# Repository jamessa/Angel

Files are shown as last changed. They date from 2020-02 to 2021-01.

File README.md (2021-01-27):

# Angel (2021)

Hand wired QMK is almost ready.  https://github.com/qmk/qmk_firmware/pull/11501

A symmetric staggered ergonomic keyboard.
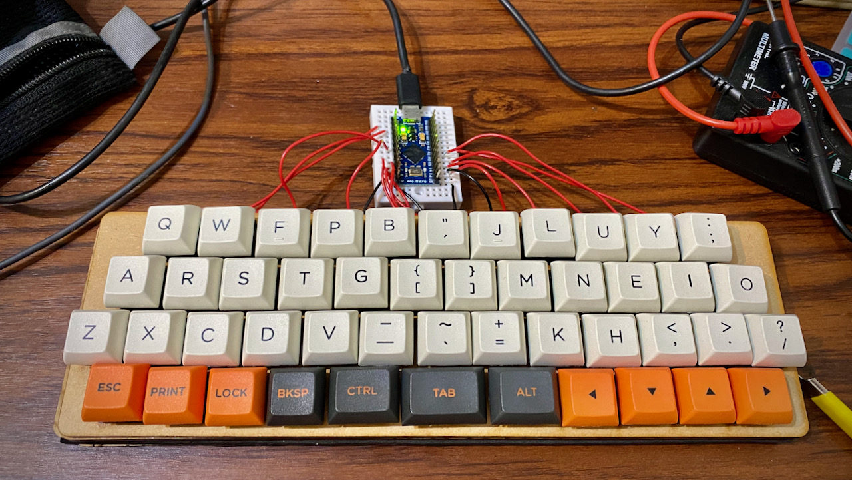
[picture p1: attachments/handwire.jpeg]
a symmetric and beautiful hand wire keyboard


## Idea

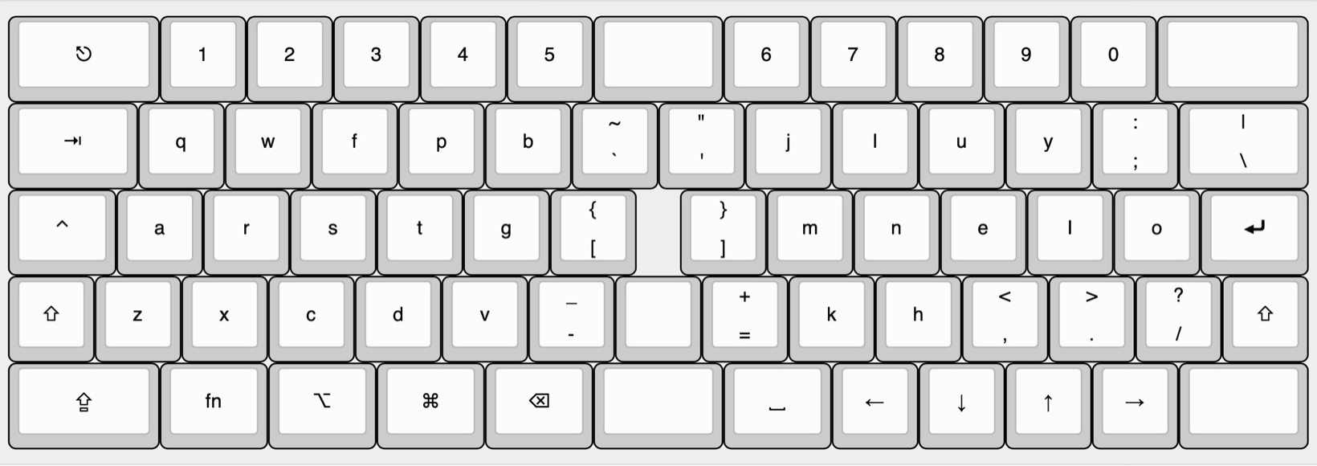
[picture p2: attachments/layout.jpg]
layout concept
A slightly ergonomic keyboard that fits into 60% form factor.  

 ## Featuring

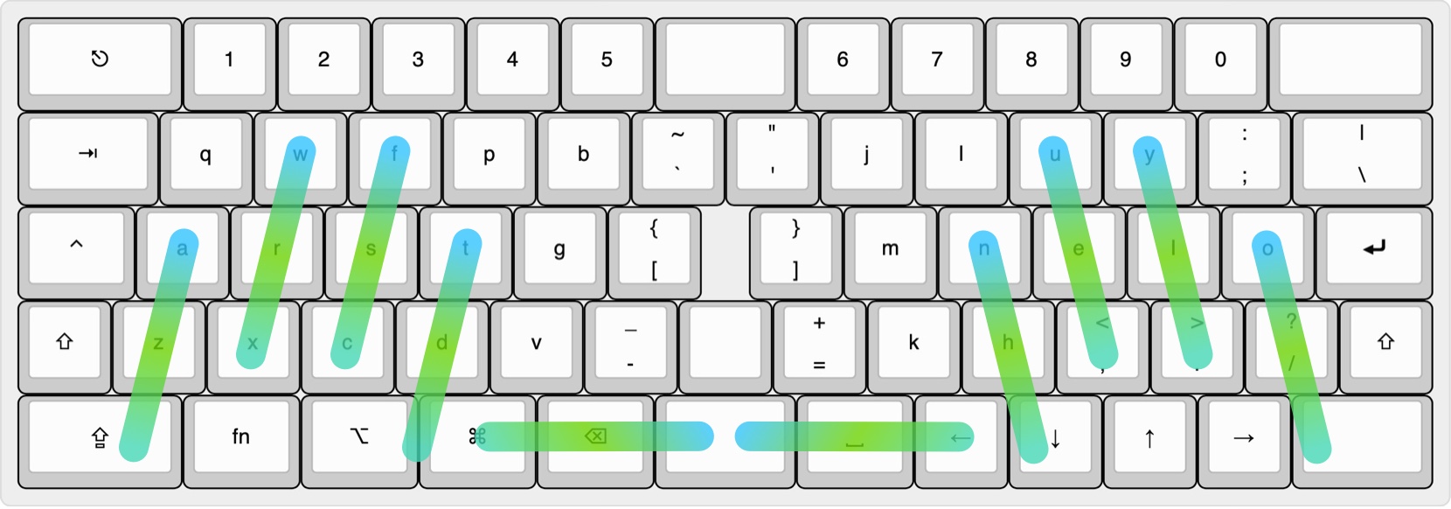
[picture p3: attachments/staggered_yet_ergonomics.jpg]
Symmetric stagger is ergonomic
* Staggered yet ergonmic 

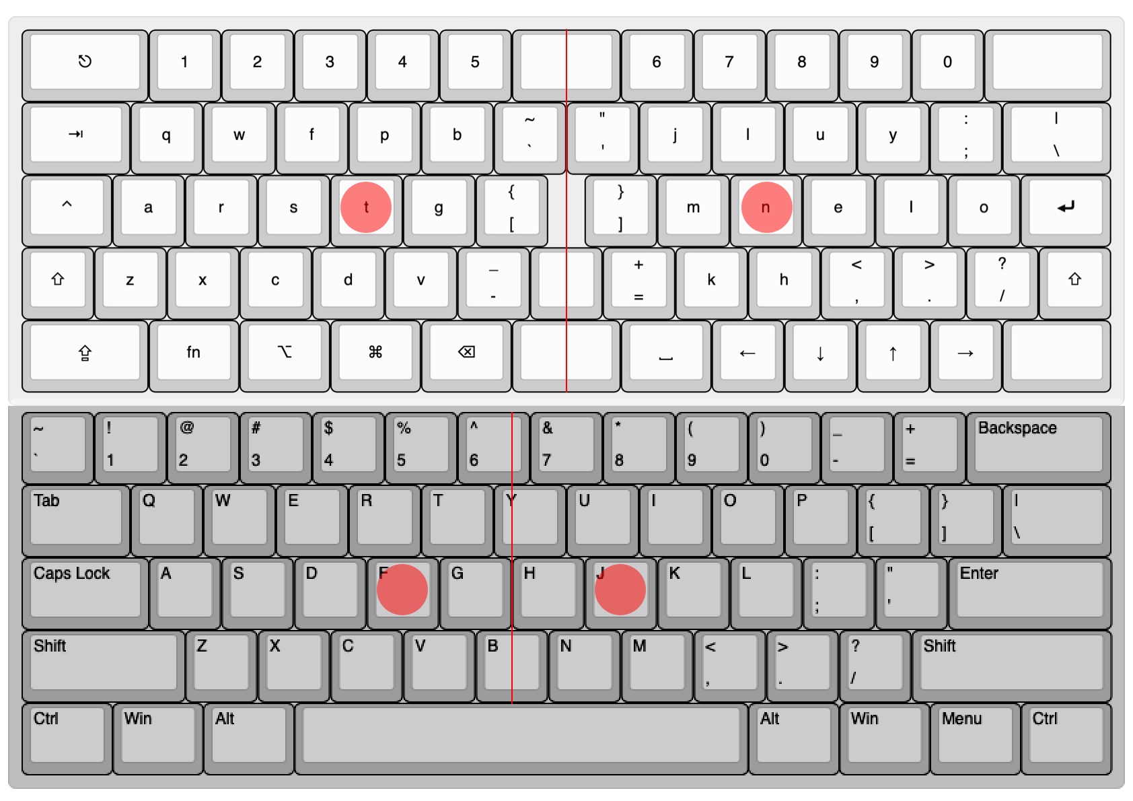
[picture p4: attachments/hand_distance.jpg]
hand distance
* Maximize hand distance 

* Arrow keys are must.

* Fitts' law is respected. Four corner keys are maximized while [you shall no call its name] is break into 3 keys.  The gaint space bar is a huge waste ot thumb(s). It breaks into 1.25, 1.5, 1.25 to free it up. My favorite combination is, <kbd>backspace</kbd>, <kbd>enter</kbd>, <kbd>whitespace</kbd>.

* 60% form factor which should fix your notebook perfectly.
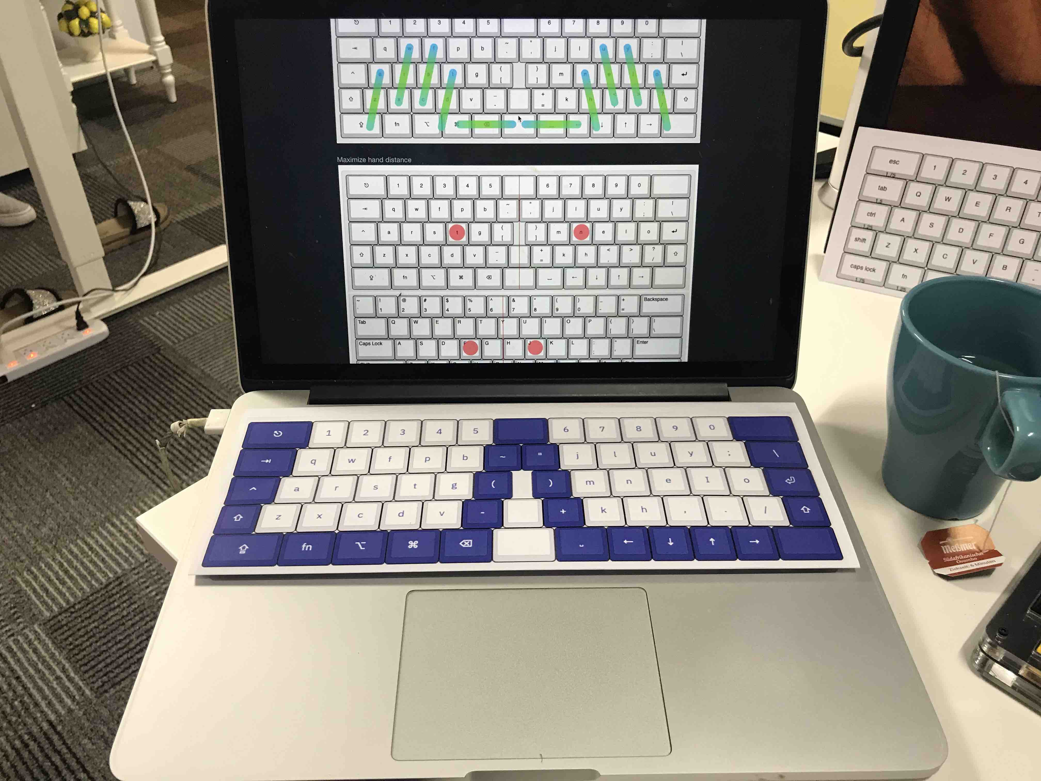
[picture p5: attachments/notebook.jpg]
notebook


* all keys are under 1.75u which means no stablizer is required. Period.

##  Cons

It's incompatible to traditioal keycaps layout. **CAPS LOCK** is the only 1.75u key on traditional keyboard. In Symmetric 60%, 4 is required but you can always swap into smaller keycaps at your wish.

## Prior work

in the order of first appearance.

[Symmetric Stagger 60%]( https://geekhack.org/index.php?topic=66965.0)  by Jesse Vincent, Keyboardio Symmetric Stagger While I wait for the Model 01 boards to come back from Shenzhen, I've been messing around with a symmetric stagger 60% layout. Before I go and get 5 PCBs made, I'd love layout feedback from folks.

### Meti
[SemiErgo](https://github.com/mtei/SemiErgo_Layout) by meti (March 2017)   SemiErgo I will vote it for ANSI standard without any doubt.

[Symmetric 70 hand-wire](https://github.com/qmk/qmk_firmware/tree/master/keyboards/handwired/symmetric70_proto) (2020)
Symmetric 70

### Rominronin
[Katana 60](https://deskthority.net/viewtopic.php?t=16287&start=30) (Nov, 2017). it's a beauty. Katana 60 ps. the character in the middle is 刀 which means sword in Chinese and Japanese.

[Tsuka60 - the Katana60 v2 PCB interest check](https://geekhack.org/index.php?topic=100468.msg2756587#msg2756587) (2019)

[Candykeys](https://candykeys.com/product/katana60-pcb-V2) (2020)

Katana60 v2 PCB
## Next

Now I am going to handwire one to refuse my point. Stay tune.

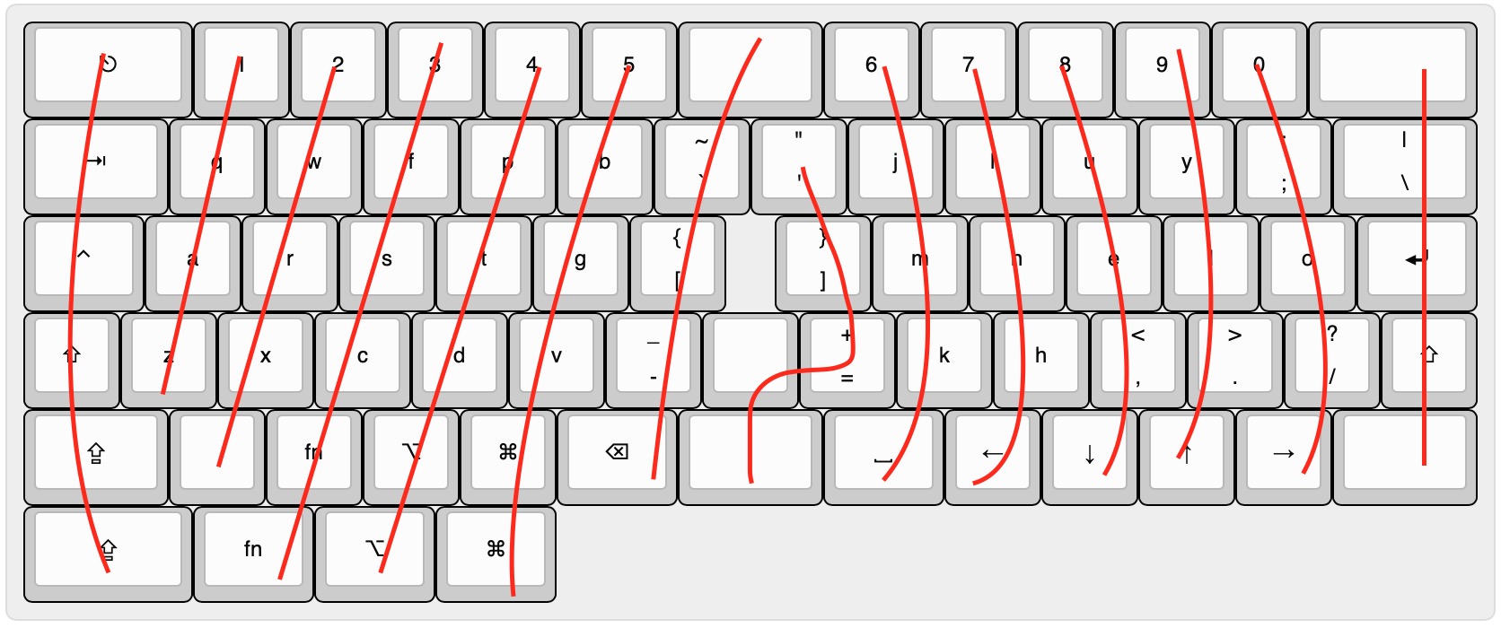
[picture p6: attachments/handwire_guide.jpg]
handwire guide


You can [try it on paper](try_it.pdf) and [let me know](https://forms.gle/i4KZJjDPFTidD8Jt6) how to you think about Symmetric60.

## References

On space bar http://xahlee.info/kbd/keyboard_problems.html

Key symbols from http://xahlee.info/comp/unicode_computing_symbols.html

Mac keyboard shortcuts https://support.apple.com/en-us/HT201236

Human Engineering the Keyboard by K. H. Eberhard Kroemer
 Human Factors: The Journal of the Human Factors and Ergonomics Society 1972 14: 51 DOI: [10.1177/001872087201400110](
http://hfs.sagepub.com/content/14/1/51)

## Prototyping Tips

### Kicad

  - Hardware acceleration will eeschema freezes, so don't enable it. Reset settings by `rm -rf ~/Library/Preferences/kicad` or verisioning it.
  - Plot gerber files and drills based on [JCLPCB's tutorial](https://support.jlcpcb.com/article/102-kicad-515---generating-gerber-and-drill-files). [Suggested naming patterns](https://support.jlcpcb.com/article/29-suggested-naming-patterns)

Special thanks to Haway 梁, Jeff 邱, Justin 吳.

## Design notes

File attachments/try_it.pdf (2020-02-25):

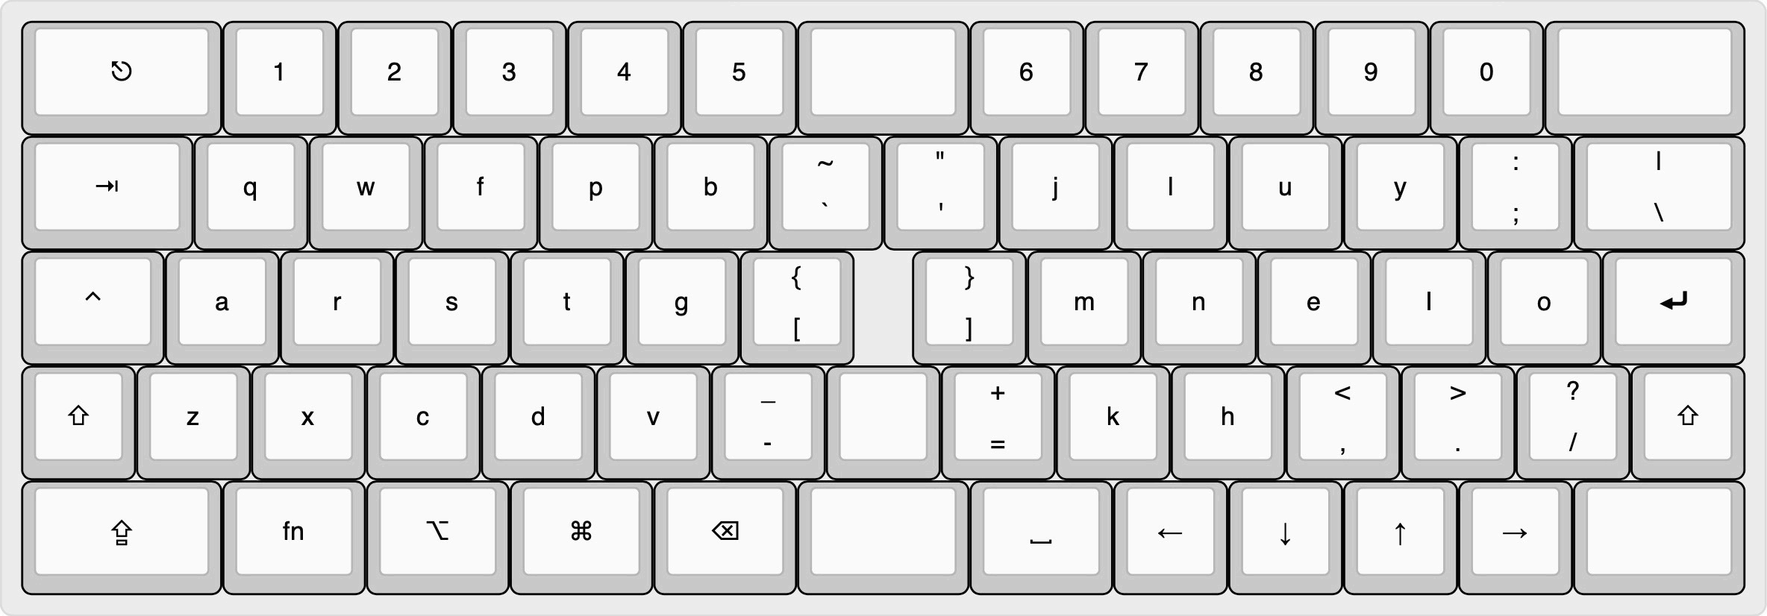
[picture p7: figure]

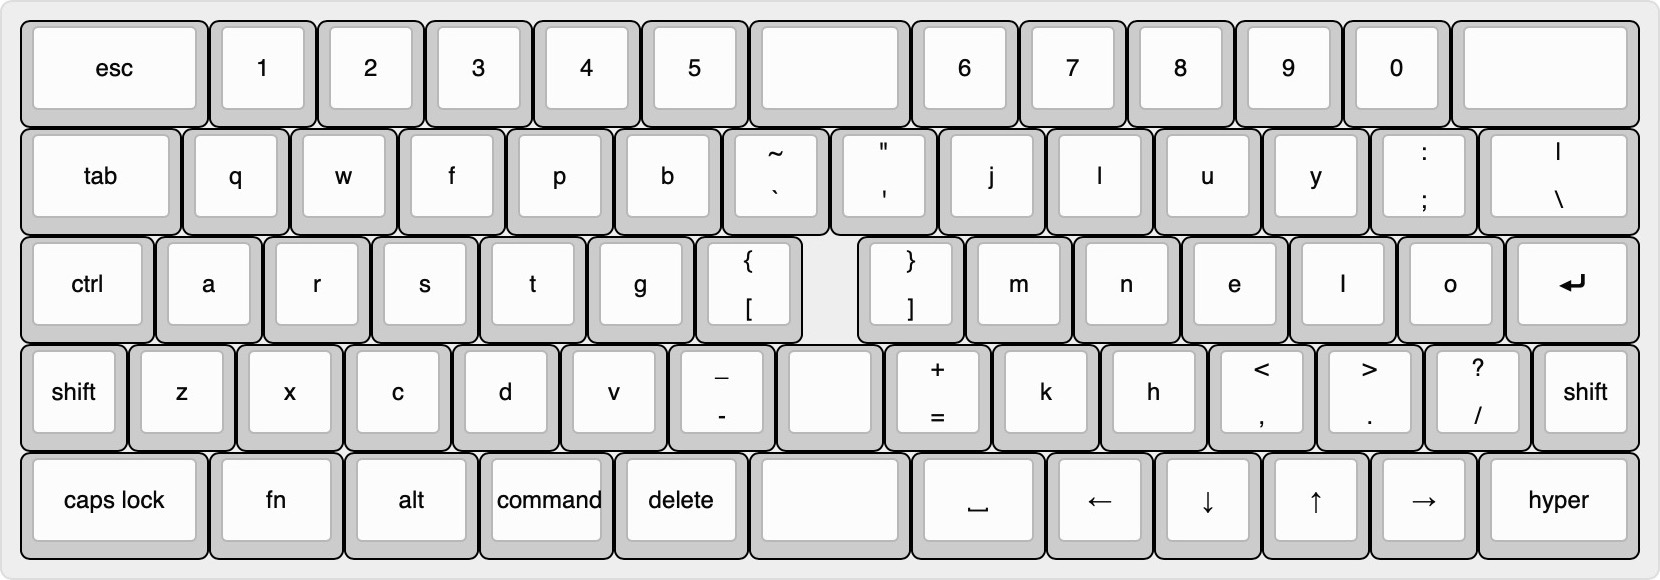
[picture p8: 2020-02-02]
attachments/symmetry_layout.jpg

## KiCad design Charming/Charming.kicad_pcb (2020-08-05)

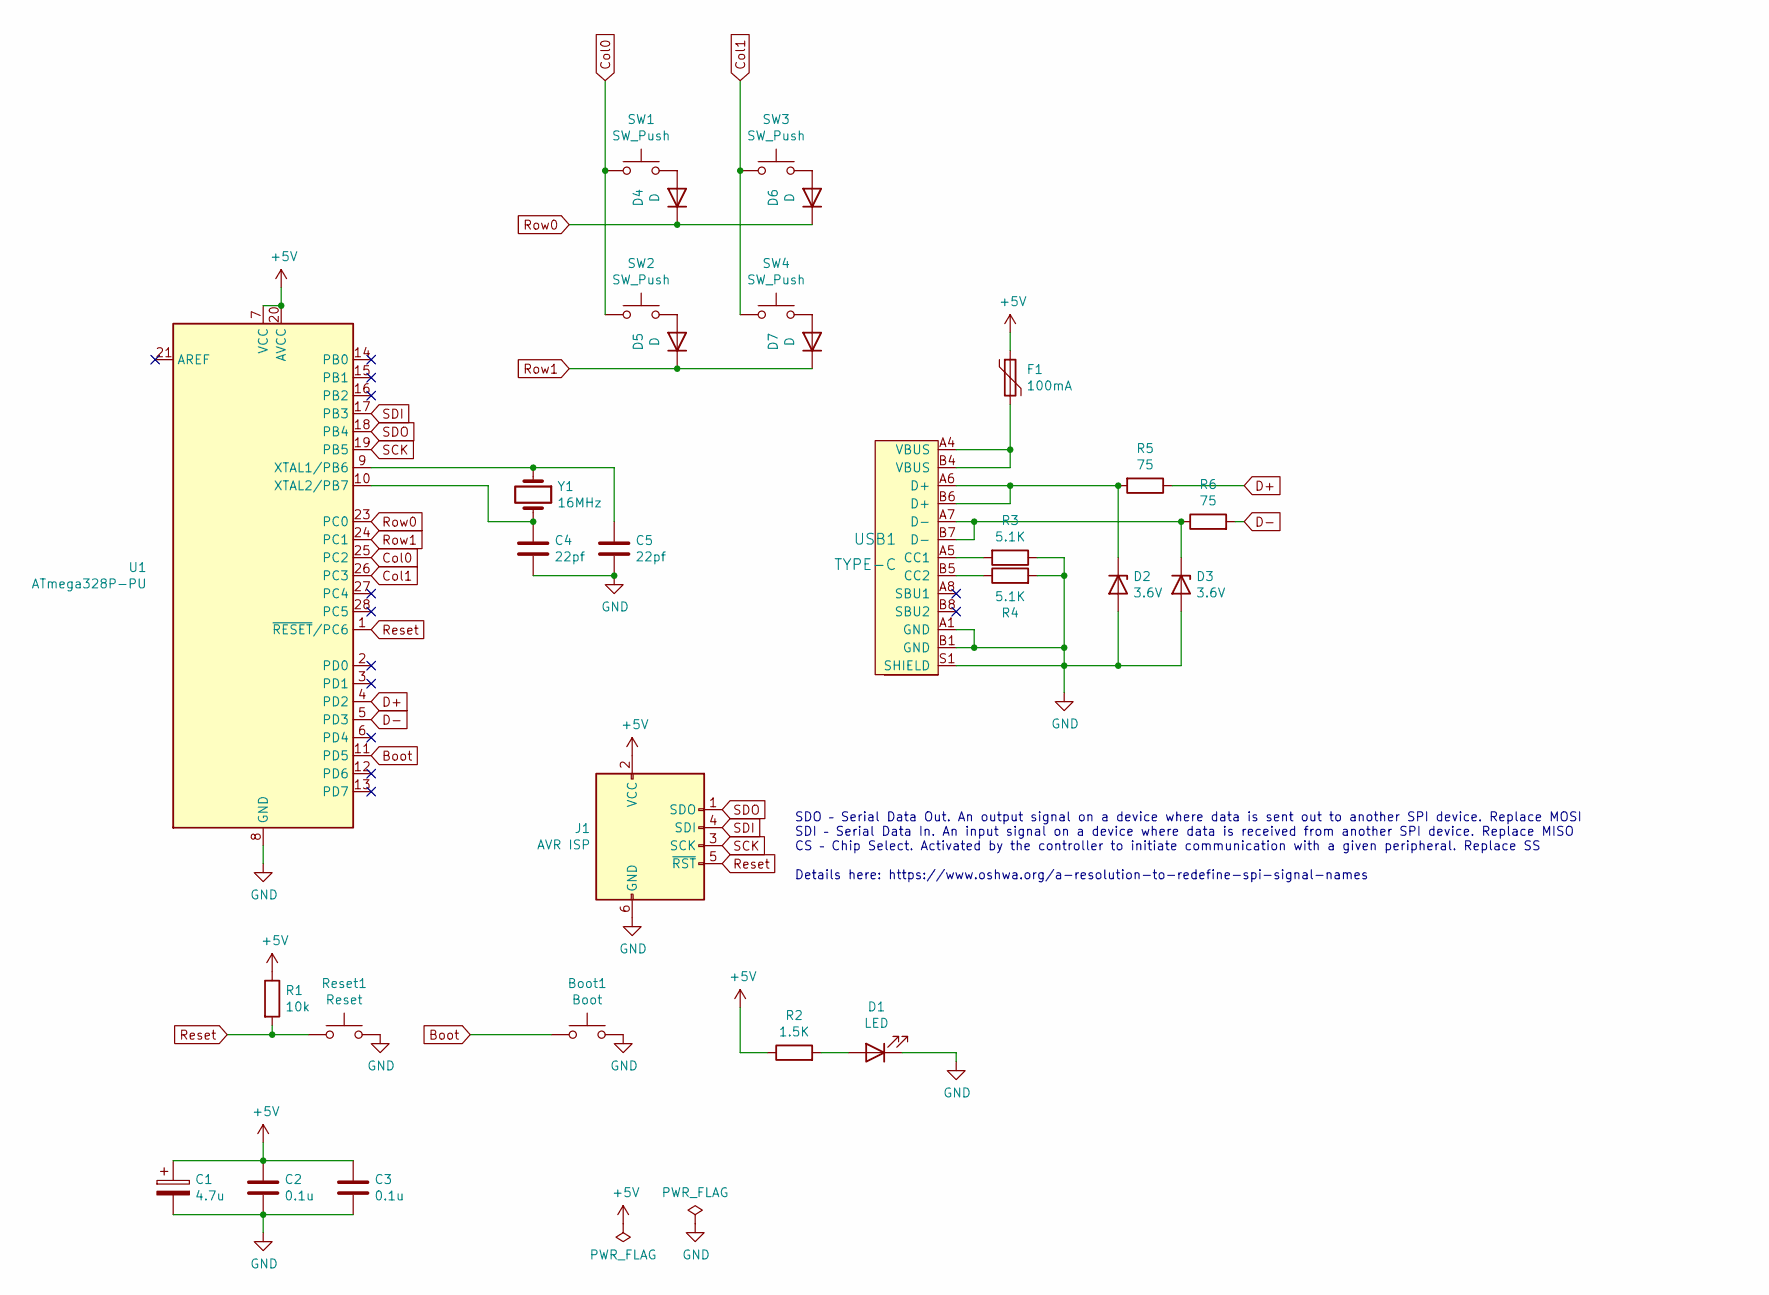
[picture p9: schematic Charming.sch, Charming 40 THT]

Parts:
Boot1: Boot; SW_PUSH_6mm
C1: 4.7u; CP_Radial_D4.0mm_P1.50mm
C2, C3: 0.1u; C_Disc_D4.3mm_W1.9mm_P5.00mm
C4, C5: 22pf; C_Disc_D3.0mm_W1.6mm_P2.50mm
D1: LED; LED_D3.0mm
D2, D3: 3.6V; D_DO-35_SOD27_P7.62mm_Horizontal
D4, D5, D6, D7: D; D_DO-35_SOD27_P7.62mm_Horizontal
F1: 100mA; Fuse_Bourns_MF-RG500
J1: AVR ISP; AVRISP
R1: 10k; R_Axial_DIN0204_L3.6mm_D1.6mm_P5.08mm_Horizontal
R2: 1.5K; R_Axial_DIN0204_L3.6mm_D1.6mm_P5.08mm_Horizontal
R3, R4: 5.1K; R_Axial_DIN0204_L3.6mm_D1.6mm_P5.08mm_Horizontal
R5, R6: 75; R_Axial_DIN0204_L3.6mm_D1.6mm_P5.08mm_Horizontal
Reset1: Reset; SW_PUSH_6mm
SW1, SW2, SW3, SW4: SW_Push; SW_Cherry_MX_1.00u_PCB
U1: ATmega328P-PU; DIP-28_W7.62mm
USB1: TYPE-C; USB_C_Receptacle_HRO_TYPE-C-31-M-12
Y1: 16MHz; Crystal_HC49-4H_Vertical

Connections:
+5V: C1.1, C2.1, C3.1, F1.1, J1.2 (VCC), R1.1, R2.1, U1.7 (VCC), U1.20 (AVCC)
Boot: Boot1.1, U1.11 (PD5)
Col0: SW1.1, SW2.1, U1.25 (PC2)
Col1: SW3.1, SW4.1, U1.26 (PC3)
D+: R5.1, U1.4 (PD2)
D-: R6.2, U1.5 (PD3)
GND: Boot1.2, C1.2, C2.2, C3.2, C4.1, C5.1, D1.1 (K), D2.2 (A), D3.2 (A), J1.6 (GND), R3.1, R4.2, Reset1.2, U1.8 (GND), U1.22 (GND), USB1.A1 (GND), USB1.B1 (GND), USB1.S1 (SHIELD)
unnamed: C4.2, U1.10 (XTAL2/PB7), Y1.2
unnamed: C5.2, U1.9 (XTAL1/PB6), Y1.1
unnamed: D1.2 (A), R2.2
unnamed: D2.1 (K), R5.2, USB1.A6 (D+), USB1.B6 (D+)
unnamed: D3.1 (K), R6.1, USB1.A7 (D-), USB1.B7 (D-)
unnamed: D4.2 (A), SW1.2
unnamed: D5.2 (A), SW2.2
unnamed: D6.2 (A), SW3.2
unnamed: D7.2 (A), SW4.2
unnamed: F1.2, USB1.A4 (VBUS), USB1.B4 (VBUS)
unnamed: R3.2, USB1.A5 (CC1)
unnamed: R4.1, USB1.B5 (CC2)
Reset: J1.5 (~RST), R1.2, Reset1.1, U1.1 (~RESET~/PC6)
Row0: D4.1 (K), D6.1 (K), U1.23 (PC0)
Row1: D5.1 (K), D7.1 (K), U1.24 (PC1)
SCK: J1.3 (SCK), U1.19 (PB5)
SDI: J1.4 (SDI), U1.17 (PB3)
SDO: J1.1 (SDO), U1.18 (PB4)

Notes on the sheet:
SDO – Serial Data Out. An output signal on a device where data is sent out to another SPI device. Replace MOSI SDI – Serial Data In. An input signal on a device where data is received from another SPI device. Replace MISO CS – Chip Select. Activated by the controller to initiate communication with 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

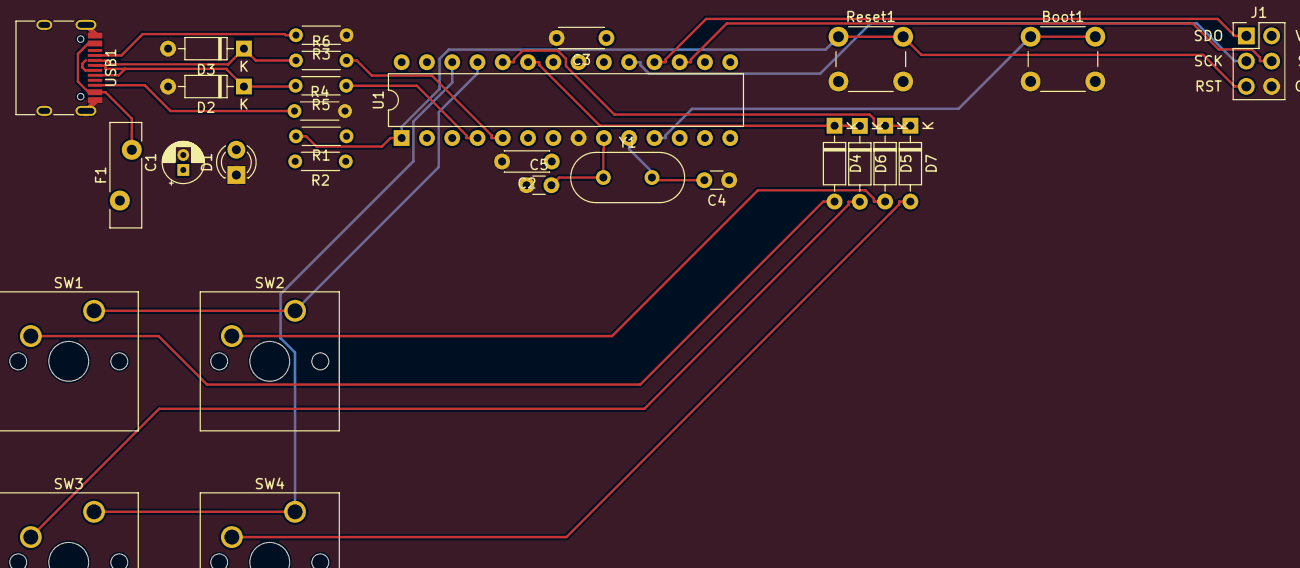
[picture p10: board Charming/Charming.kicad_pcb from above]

Board: 2 copper layers, 29 parts (0 on the bottom side), 25 nets.

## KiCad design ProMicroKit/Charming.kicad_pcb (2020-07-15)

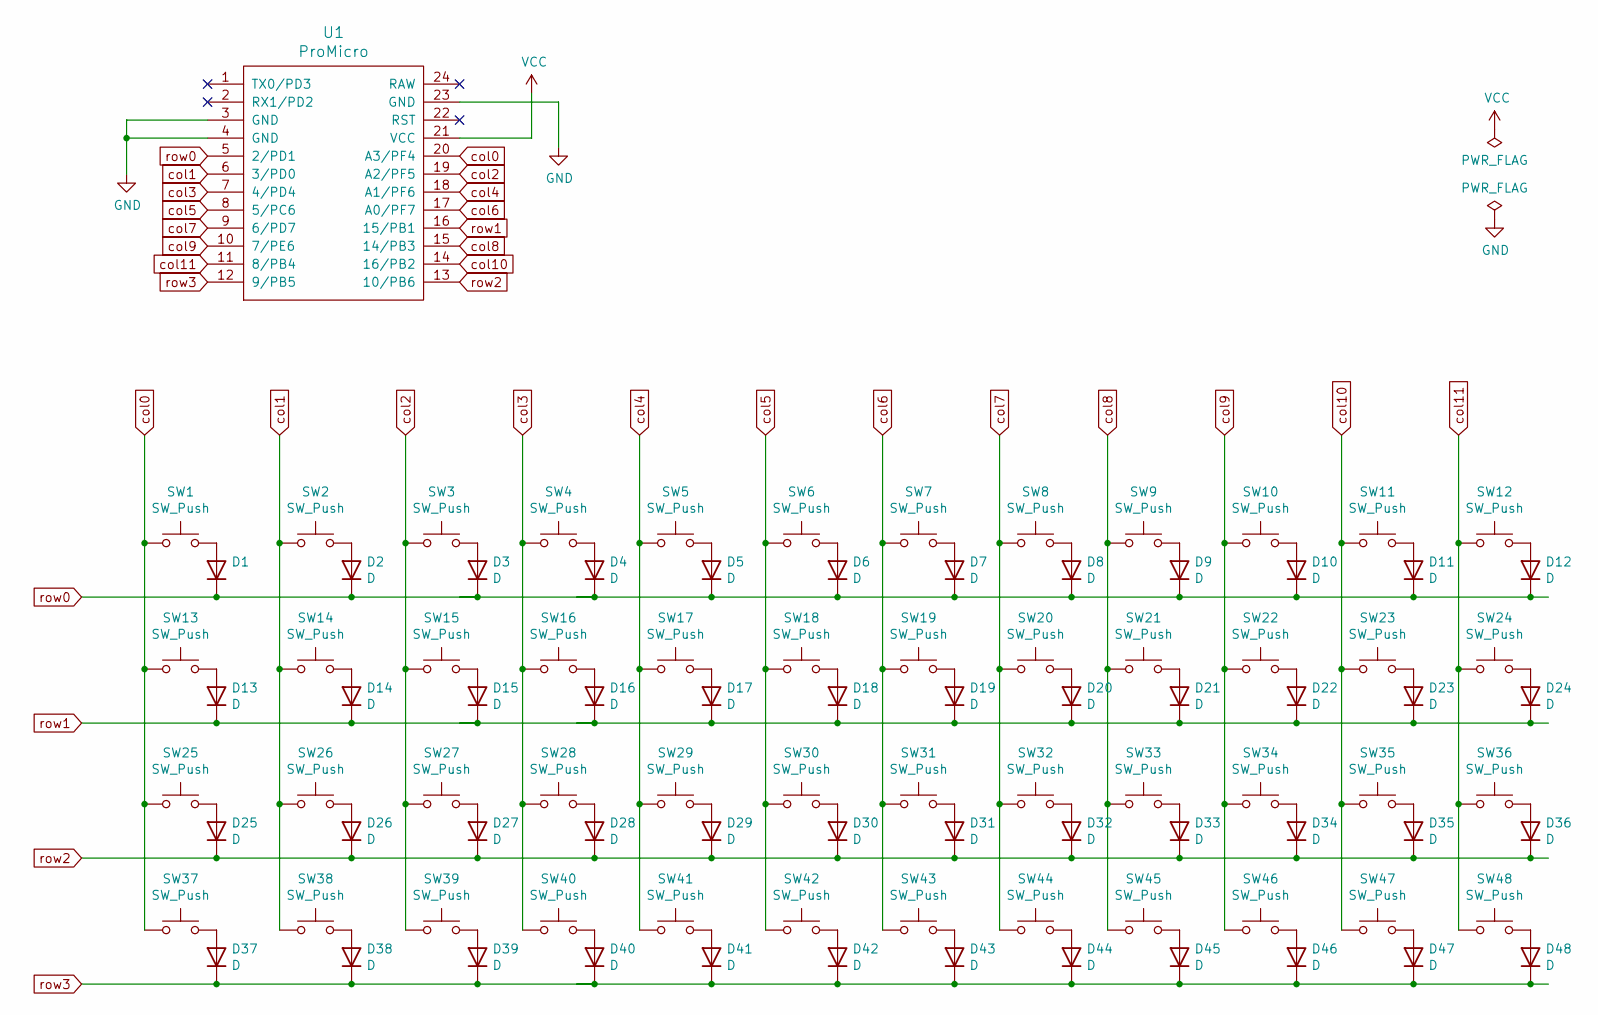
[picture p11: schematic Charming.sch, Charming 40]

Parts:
D1, D2, D3, D4, D5, D6, D7, D8, D9, D10, D11, D12, D13, D14, D15, D16, D17, D18, D19, D20, D21, D22, D23, D24, D25, D26, D27, D28, D29, D30, D31, D32, D33, D34, D35, D36, D37, D38, D39, D40, D41, D42, D43, D44, D45, D46, D47, D48: D; D_SOD-123
SW1, SW2, SW3, SW4, SW5, SW6, SW7, SW8, SW9, SW10, SW11, SW12, SW13, SW14, SW15, SW16, SW17, SW18, SW19, SW20, SW21, SW22, SW23, SW24, SW25, SW26, SW27, SW28, SW29, SW30, SW31, SW32, SW33, SW34, SW35, SW36, SW37, SW38, SW39, SW40, SW41, SW42, SW43, SW44, SW45, SW46, SW47, SW48: SW_Push; SW_PG1350
U1: ProMicro; ArduinoProMicro

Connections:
GND: U1.3 (GND), U1.4 (GND), U1.23 (GND)
unnamed: D1.2 (A), SW1.2
unnamed: D2.2 (A), SW2.2
unnamed: D3.2 (A), SW3.2
unnamed: D4.2 (A), SW4.2
unnamed: D5.2 (A), SW5.2
unnamed: D6.2 (A), SW6.2
unnamed: D7.2 (A), SW7.2
unnamed: D8.2 (A), SW8.2
unnamed: D9.2 (A), SW9.2
unnamed: D10.2 (A), SW10.2
unnamed: D11.2 (A), SW11.2
unnamed: D12.2 (A), SW12.2
unnamed: D13.2 (A), SW13.2
unnamed: D14.2 (A), SW14.2
unnamed: D15.2 (A), SW15.2
unnamed: D16.2 (A), SW16.2
unnamed: D17.2 (A), SW17.2
unnamed: D18.2 (A), SW18.2
unnamed: D19.2 (A), SW19.2
unnamed: D20.2 (A), SW20.2
unnamed: D21.2 (A), SW21.2
unnamed: D22.2 (A), SW22.2
unnamed: D23.2 (A), SW23.2
unnamed: D24.2 (A), SW24.2
unnamed: D25.2 (A), SW25.2
unnamed: D26.2 (A), SW26.2
unnamed: D27.2 (A), SW27.2
unnamed: D28.2 (A), SW28.2
unnamed: D29.2 (A), SW29.2
unnamed: D30.2 (A), SW30.2
unnamed: D31.2 (A), SW31.2
unnamed: D32.2 (A), SW32.2
unnamed: D33.2 (A), SW33.2
unnamed: D34.2 (A), SW34.2
unnamed: D35.2 (A), SW35.2
unnamed: D36.2 (A), SW36.2
unnamed: D37.2 (A), SW37.2
unnamed: D38.2 (A), SW38.2
unnamed: D39.2 (A), SW39.2
unnamed: D40.2 (A), SW40.2
unnamed: D41.2 (A), SW41.2
unnamed: D42.2 (A), SW42.2
unnamed: D43.2 (A), SW43.2
unnamed: D44.2 (A), SW44.2
unnamed: D45.2 (A), SW45.2
unnamed: D46.2 (A), SW46.2
unnamed: D47.2 (A), SW47.2
unnamed: D48.2 (A), SW48.2
VCC: U1.21 (VCC)
col0: SW1.1, SW13.1, SW25.1, SW37.1, U1.20 (A3/PF4)
col1: SW2.1, SW14.1, SW26.1, SW38.1, U1.6 (3/PD0)
col2: SW3.1, SW15.1, SW27.1, SW39.1, U1.19 (A2/PF5)
col3: SW4.1, SW16.1, SW28.1, SW40.1, U1.7 (4/PD4)
col4: SW5.1, SW17.1, SW29.1, SW41.1, U1.18 (A1/PF6)
col5: SW6.1, SW18.1, SW30.1, SW42.1, U1.8 (5/PC6)
col6: SW7.1, SW19.1, SW31.1, SW43.1, U1.17 (A0/PF7)
col7: SW8.1, SW20.1, SW32.1, SW44.1, U1.9 (6/PD7)
col8: SW9.1, SW21.1, SW33.1, SW45.1, U1.15 (14/PB3)
col9: SW10.1, SW22.1, SW34.1, SW46.1, U1.10 (7/PE6)
col10: SW11.1, SW23.1, SW35.1, SW47.1, U1.14 (16/PB2)
col11: SW12.1, SW24.1, SW36.1, SW48.1, U1.11 (8/PB4)
row0: D1.1 (K), D2.1 (K), D3.1 (K), D4.1 (K), D5.1 (K), D6.1 (K), D7.1 (K), D8.1 (K), D9.1 (K), D10.1 (K), D11.1 (K), D12.1 (K), U1.5 (2/PD1)
row1: D13.1 (K), D14.1 (K), D15.1 (K), D16.1 (K), D17.1 (K), D18.1 (K), D19.1 (K), D20.1 (K), D21.1 (K), D22.1 (K), D23.1 (K), D24.1 (K), U1.16 (15/PB1)
row2: D25.1 (K), D26.1 (K), D27.1 (K), D28.1 (K), D29.1 (K), D30.1 (K), D31.1 (K), D32.1 (K), D33.1 (K), D34.1 (K), D35.1 (K), D36.1 (K), U1.13 (10/PB6)
row3: D37.1 (K), D38.1 (K), D39.1 (K), D40.1 (K), D41.1 (K), D42.1 (K), D43.1 (K), D44.1 (K), D45.1 (K), D46.1 (K), D47.1 (K), D48.1 (K), U1.12 (9/PB5)

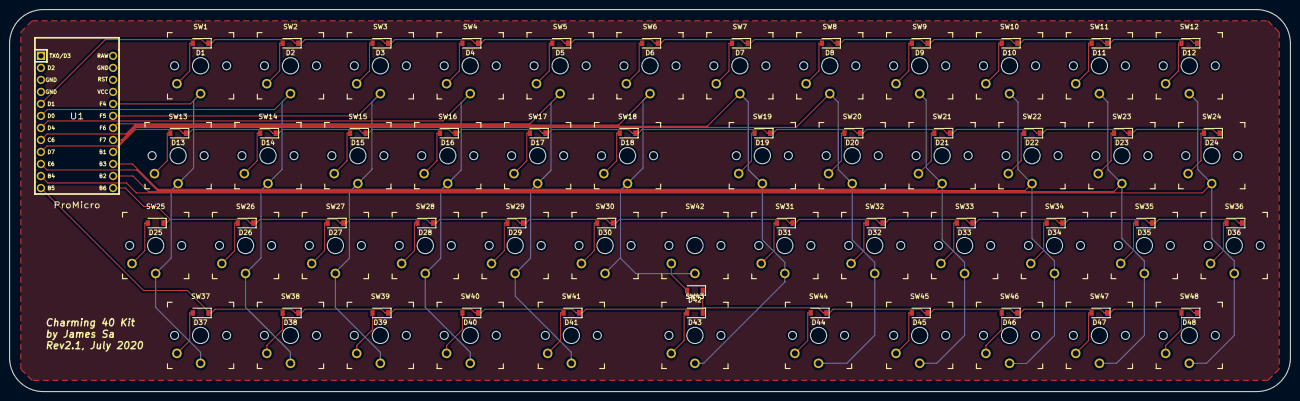
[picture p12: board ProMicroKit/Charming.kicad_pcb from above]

Board: 2 copper layers, 270.8 x 80.8 mm, 97 parts (0 on the bottom side), 65 nets.

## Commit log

2020-06-17 keyboard matrix ok
    [Charming.kicad_pcb, Charming.sch]
2020-06-17 all components on but routing failed
    [Charming.kicad_pcb]
2020-06-17 3d view is back
    [Charming.kicad_pcb]
2020-06-17 update PG13500 footprint
    [Charming.kicad_pcb, Charming.sch]
2020-06-17 before row col changle
    [Charming.kicad_pcb, Charming.sch]
2020-06-17 add switch and promicro courtyard
    [Charming-B_Cu.gbr, Charming-B_SilkS.gbr, Charming-Edge_Cuts.gbr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]
2020-06-18 update output file
    [Charming-B_Cu.gbr, Charming-B_Mask.gbr, Charming-B_SilkS.gbr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]
2020-06-20 change diode connector position
    [Charming.kicad_pcb, Charming.sch]
2020-06-20 nice and clean signal lines
    [Charming.kicad_pcb, Charming.sch]
2020-06-21 bring back DRC by providing courtyard
    [Charming.kicad_pcb]
2020-06-22 even odd pins
    [Charming.kicad_pcb, Charming.sch]
2020-06-22 export new gerber
    [Charming-B_Cu.gbr, Charming-B_Mask.gbr, Charming-B_SilkS.gbr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]
2020-07-15 Kicad routing practice
    [Charming.kicad_pcb]
2020-07-31 new layout
    [Charming-B_Cu.gbr, Charming-B_Mask.gbr, Charming-B_SilkS.gbr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]
2020-08-04 customize symbol and footprint
    [Charming.kicad_pcb, Charming.sch]
2020-08-05 add 3D model
    [Charming.kicad_pcb]
